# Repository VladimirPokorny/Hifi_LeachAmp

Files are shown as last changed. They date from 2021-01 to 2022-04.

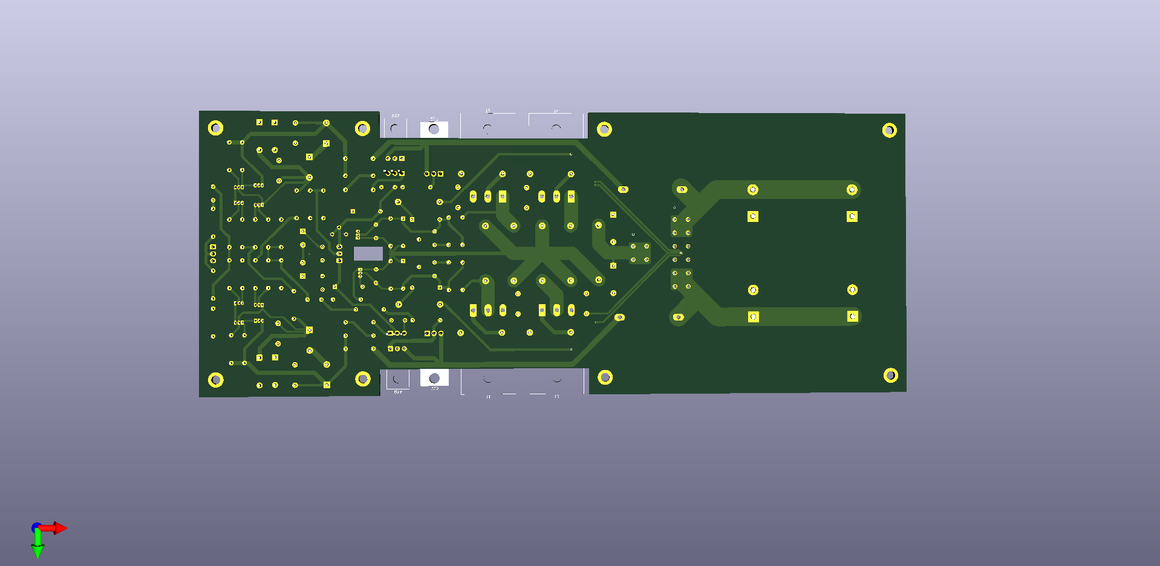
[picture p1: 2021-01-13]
LeachAmp_kicad/export_obr/3D_pohled_2.png

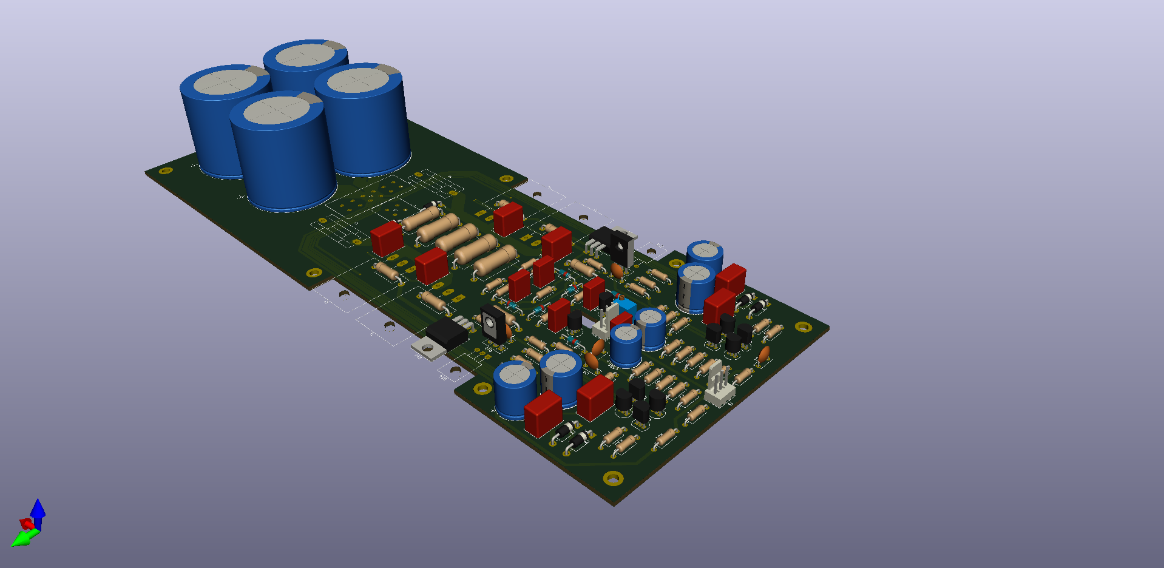
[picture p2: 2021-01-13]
LeachAmp_kicad/export_obr/3D_pohled_3.png

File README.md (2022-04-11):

# Hifi_LeachAmp

Design of low frequency audio amplifier designed by Prof. Leach from Georgia Institute of Technology.
Main resource: https://leachlegacy.ece.gatech.edu/lowtim/

The PCB is designated in freeware software KiCAD. https://www.kicad.org/

The project is not finished yet. It has been put on hold due to work on the Master's thesis.

LeachAmp

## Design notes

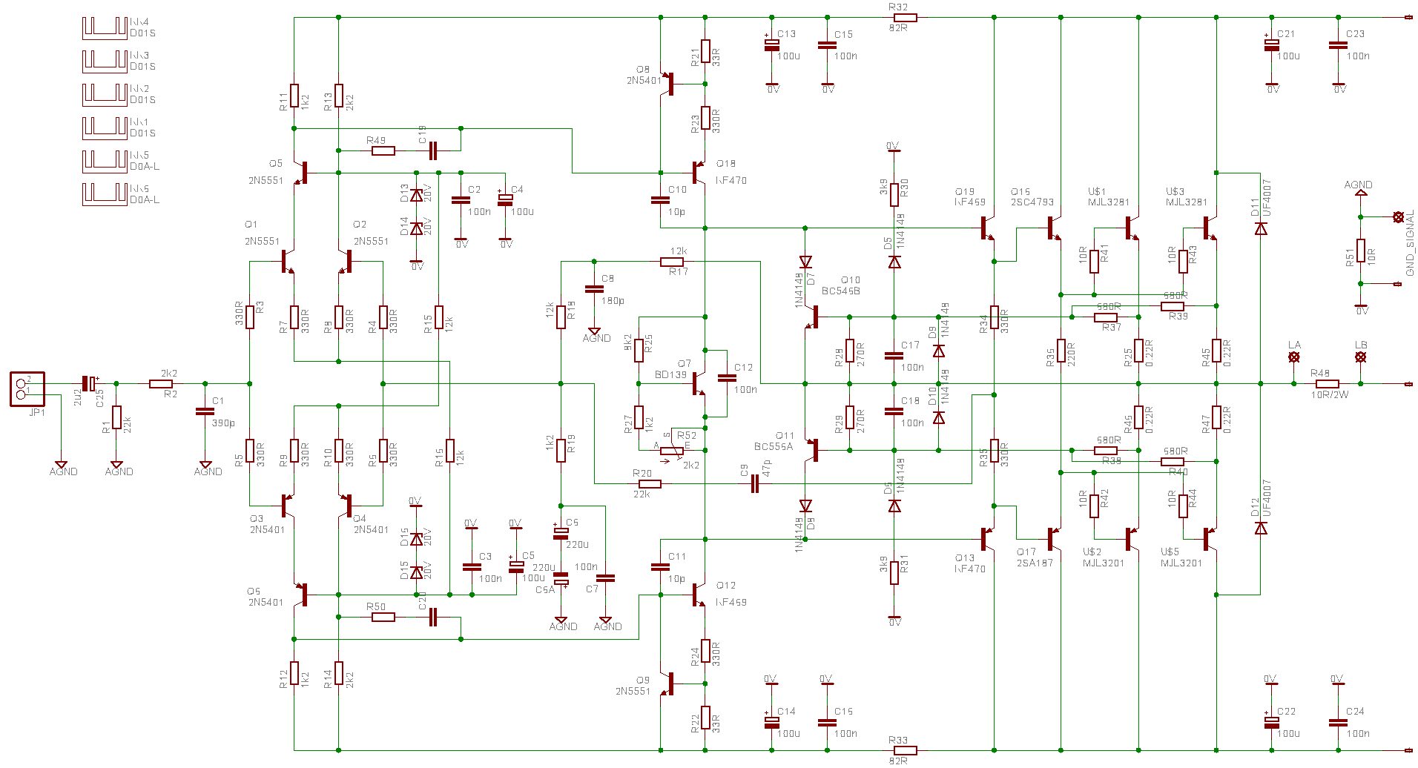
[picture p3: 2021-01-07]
Podklady/Levex_Leach_schema.PNG

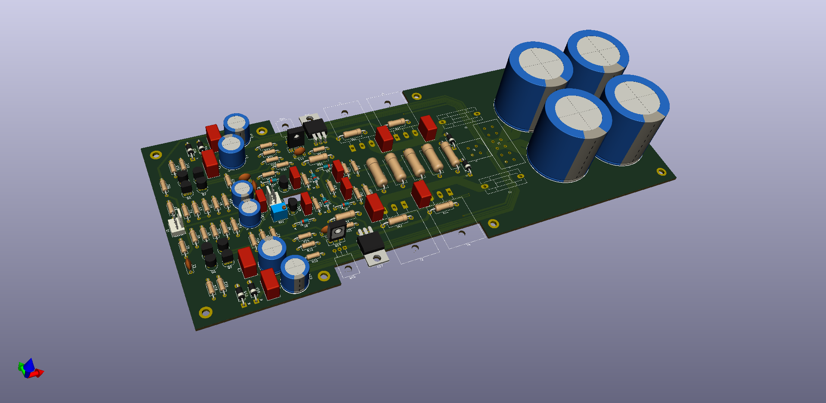
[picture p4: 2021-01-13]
LeachAmp_kicad/export_obr/3D_pohled_1.png

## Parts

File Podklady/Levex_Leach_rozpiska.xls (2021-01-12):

Rozpiska součástek pro Leach LV-edition
Označení | Hodnota | Popis
C1 | 390p | RM=5
C2 | 100n/50V | RM=5
C3 | 100n/50V | RM=5
C4 | 100u/63V | RM=5
C5 | 100u/63V | RM=5
C6 | 100u/63V | RM=5 (nebo osadit bipolárním a C6A spojit propojkou)
C6A | 100u/63V | RM=5
C7 | 100n | RM=5 (fóliový)
C8 | 180p | RM=5
C9 | 47p | RM=5
C10 | 10p/500V | RM=5
C11 | 10p/500V | RM=5
C12 | 100n/50V | RM=5
C13 | 100u/63V | RM=5
C14 | 100u/63V | RM=5
C15 | 100n/63V | RM=5
C16 | 100n/63V | RM=5
C17 | 100n/50V | RM=5
C18 | 100n/50V | RM=5
C19 | NEOSAZ. | 0805
C20 | NEOSAZ. | 0805
C21 | 100u/min 63V | RM=5
C22 | 100u/min 63V | RM=5
C23 | 100n/min 63V | RM=5
C24 | 100n/min 63V | RM=5
C25 | 2u2/35V | RM=2,5
D5 | 1N4148 | RM=10
D6 | 1N4148 | RM=10
D7 | 1N4148 | RM=10
D8 | 1N4148 | RM=10
D9 | 1N4148 | RM=10
D10 | 1N4148 | RM=10
D11 | UF4007 | RM=10
D12 | UF4007 | RM=10
D13 | ZD20V | RM=10
D14 | ZD20V | RM=10
D15 | ZD20V | RM=10
D16 | ZD20V | RM=10
Q1 | BC546B | (nebo 2N5551 - ale otočit o 180°)
Q2 | BC546B | (nebo 2N5551 - ale otočit o 180°)
Q3 | BC556B | (nebo 2N5401 - ale otočit o 180°)
Q4 | BC556B | (nebo 2N5401 - ale otočit o 180°)
Q5 | BC546B | (nebo 2N5551 - ale otočit o 180°)
Q6 | BC556B | (nebo 2N5401 - ale otočit o 180°)
Q7 | KF469 | případně BF469 nebo BF471)
Q8 | BC556B | (nebo 2N5401 - ale otočit o 180°)
Q9 | BC546B | (nebo 2N5551 - ale otočit o 180°)
Q10 | BC546B | (nebo 2N5551 - ale otočit o 180°)
Q11 | BC556B | (nebo 2N5401 - ale otočit o 180°)
Q12 | KF469 | případně BF469 nebo BF471)
Q13 | KF470 | případně BF470 nebo BF472)
Q16 | 2SC4793 | TO-220
Q17 | 2SA1837 | TO-220
Q18 | KF470 | případně BF470 nebo BF472)
Q19 | KF469 | případně BF469 nebo BF471)
R1 | 22k | RM=10
R2 | 2k2 | RM=10
R3 | 330R | RM=10
R4 | 330R | RM=10
R5 | 330R | RM=10
R6 | 330R | RM=10
R7 | 330R | RM=10
R8 | 330R | RM=10
R9 | 330R | RM=10
R10 | 330R | RM=10
R11 | 1k2 | RM=10
R12 | 1k2 | RM=10
R13 | 2k2 | RM=12
R14 | 2k2 | RM=12
R15 | 12k | RM=10
R16 | 12k | RM=10
R17 | 12k | RM=10
R18 | 12k | RM=10
R19 | 1k2 | RM=10
R20 | 22k | RM=10
R21 | 33R | RM=10
R22 | 33R | RM=10
R23 | 330R | RM=10
R24 | 330R | RM=10
R25 | 0.22R/4W | RM=15
R26 | 8k2 | RM=10 (pokud bude klidový proud velký, tento odpor zmenšit)
R27 | 1k2 | RM=10
R28 | 270R | RM=10
R29 | 270R | RM=10
R30 | 3k9 | RM=12
R31 | 3k9 | RM=12
R32 | 82R | RM=10
R33 | 82R | RM=10
R34 | 330R | RM=10
R35 | 330R | RM=10
R36 | 220R | RM=10
R37 | 680R | RM=10
R38 | 680R | RM=10
R39 | 680R | RM=10
R40 | 680R | RM=10
R41 | 10R/2W | RM=12
R42 | 10R/2W | RM=12
R43 | 10R/2W | RM=12
R44 | 10R/2W | RM=12
R45 | 0.22R/4W | RM=15
R46 | 0.22R/4W | RM=15
R47 | 0.22R/4W | RM=15
R48 | 10R/2W | RM=15
R49 | NEOSAZ. | 0805
R50 | NEOSAZ. | 0805
R51 | 10R | RM=10
R52 | 2k5 | víceotáčkový
T1 | MJL3281A | TO-264
T2 | MJL3281A | TO-264
T3 | MJL1302A | TO-264
T4 | MJL1302A | TO-264
LA-LB | cívka | Namotat drátem d=1mm asi 12záv a nasadit na odpor R48

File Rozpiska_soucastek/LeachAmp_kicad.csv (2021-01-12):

Reference | Value | Footprint | Datasheet
R1 | 22k | Resistor_THT:R_Axial_DIN0207_L6.3mm_D2.5mm_P10.16mm_Horizontal | ~
R2 | 2k2 | Resistor_THT:R_Axial_DIN0207_L6.3mm_D2.5mm_P10.16mm_Horizontal | ~
R3 | 300R | Resistor_THT:R_Axial_DIN0207_L6.3mm_D2.5mm_P10.16mm_Horizontal | ~
R7 | 300R | Resistor_THT:R_Axial_DIN0207_L6.3mm_D2.5mm_P10.16mm_Horizontal | ~
R8 | 300R | Resistor_THT:R_Axial_DIN0207_L6.3mm_D2.5mm_P10.16mm_Horizontal | ~
R11 | 1k2 | Resistor_THT:R_Axial_DIN0207_L6.3mm_D2.5mm_P10.16mm_Horizontal | ~
R13 | 2k2 | Resistor_THT:R_Axial_DIN0207_L6.3mm_D2.5mm_P10.16mm_Horizontal | ~
D13 | 20V/0,5W | Diode_THT:D_DO-41_SOD81_P10.16mm_Horizontal | ~
D14 | 20V/0,5W | Diode_THT:D_DO-41_SOD81_P10.16mm_Horizontal | ~
R4 | 300R | Resistor_THT:R_Axial_DIN0207_L6.3mm_D2.5mm_P10.16mm_Horizontal | ~
R5 | 300R | Resistor_THT:R_Axial_DIN0207_L6.3mm_D2.5mm_P10.16mm_Horizontal | ~
R9 | 300R | Resistor_THT:R_Axial_DIN0207_L6.3mm_D2.5mm_P10.16mm_Horizontal | ~
R10 | 300R | Resistor_THT:R_Axial_DIN0207_L6.3mm_D2.5mm_P10.16mm_Horizontal | ~
R12 | 1k2 | Resistor_THT:R_Axial_DIN0207_L6.3mm_D2.5mm_P10.16mm_Horizontal | ~
R14 | 2k2 | Resistor_THT:R_Axial_DIN0207_L6.3mm_D2.5mm_P10.16mm_Horizontal | ~
R6 | 300R | Resistor_THT:R_Axial_DIN0207_L6.3mm_D2.5mm_P10.16mm_Horizontal | ~
R15 | 12k | Resistor_THT:R_Axial_DIN0207_L6.3mm_D2.5mm_P10.16mm_Horizontal | ~
R16 | 12k | Resistor_THT:R_Axial_DIN0207_L6.3mm_D2.5mm_P10.16mm_Horizontal | ~
C2 | 100n/100V film | Capacitor_THT:C_Rect_L10.3mm_W5.7mm_P7.50mm_MKS4 | ~
R19 | 1k1 | Resistor_THT:R_Axial_DIN0207_L6.3mm_D2.5mm_P10.16mm_Horizontal | ~
R18 | 1k1 | Resistor_THT:R_Axial_DIN0207_L6.3mm_D2.5mm_P10.16mm_Horizontal | ~
R21 | 30R | Resistor_THT:R_Axial_DIN0207_L6.3mm_D2.5mm_P10.16mm_Horizontal | ~
R23 | 360R | Resistor_THT:R_Axial_DIN0207_L6.3mm_D2.5mm_P10.16mm_Horizontal | ~
C10 | 10p | Capacitor_THT:C_Disc_D6.0mm_W2.5mm_P5.00mm | ~
C8 | 180p | Capacitor_THT:C_Disc_D6.0mm_W2.5mm_P5.00mm | ~
R25 | 8k2 | Resistor_THT:R_Axial_DIN0207_L6.3mm_D2.5mm_P10.16mm_Horizontal | ~
Q7 | BD139 | Package_TO_SOT_THT:TO-92_Inline | http://www.onsemi.com/pub_link/Collateral/MPSA42-D.PDF
C12 | 100n/50V film | Capacitor_THT:C_Rect_L7.2mm_W3.5mm_P5.00mm_FKS2_FKP2_MKS2_MKP2 | ~
R27 | 1k2 | Resistor_THT:R_Axial_DIN0207_L6.3mm_D2.5mm_P10.16mm_Horizontal | ~
R28 | 270R | Resistor_THT:R_Axial_DIN0207_L6.3mm_D2.5mm_P10.16mm_Horizontal | ~
R22 | 30R | Resistor_THT:R_Axial_DIN0207_L6.3mm_D2.5mm_P10.16mm_Horizontal | ~
R24 | 360R | Resistor_THT:R_Axial_DIN0207_L6.3mm_D2.5mm_P10.16mm_Horizontal | ~
C11 | 10p | Capacitor_THT:C_Disc_D6.0mm_W2.5mm_P5.00mm | ~
C4 | 100u/63V | Capacitor_THT:CP_Radial_D12.5mm_P7.50mm | ~
C3 | 100n/100V film | Capacitor_THT:C_Rect_L10.3mm_W5.7mm_P7.50mm_MKS4 | ~
C5 | 100u/63V | Capacitor_THT:CP_Radial_D12.5mm_P7.50mm | ~
C6A1 | 330u/16V | Capacitor_THT:CP_Radial_D10.0mm_P5.00mm | ~
C6B1 | 330u/16V | Capacitor_THT:CP_Radial_D10.0mm_P5.00mm | ~
C7 | 100n/50V film | Capacitor_THT:C_Rect_L7.2mm_W3.5mm_P5.00mm_FKS2_FKP2_MKS2_MKP2 | ~
C14 | 100u/63V | Capacitor_THT:CP_Radial_D12.5mm_P7.50mm | ~
C16 | 100n/100V film | Capacitor_THT:C_Rect_L10.3mm_W5.7mm_P7.50mm_MKS4 | ~
C15 | 100n/100V | Capacitor_THT:C_Rect_L10.3mm_W5.7mm_P7.50mm_MKS4 | ~
R32 | 82R | Resistor_THT:R_Axial_DIN0207_L6.3mm_D2.5mm_P10.16mm_Horizontal | ~
Q10 | MPSA06 | Package_TO_SOT_THT:TO-92_Inline | http://www.onsemi.com/pub_link/Collateral/MPSA42-D.PDF
D7 | 1N4148 | Diode_THT:D_DO-35_SOD27_P10.16mm_Horizontal | ~
Q11 | MPSA56 | Package_TO_SOT_THT:TO-92_Inline | http://www.onsemi.com/pub_link/Collateral/MPSA92-D.PDF
R29 | 270R | Resistor_THT:R_Axial_DIN0207_L6.3mm_D2.5mm_P10.16mm_Horizontal | ~
C17 | 100n/50V film | Capacitor_THT:C_Rect_L7.2mm_W3.5mm_P5.00mm_FKS2_FKP2_MKS2_MKP2 | ~
C18 | 100n/50V film | Capacitor_THT:C_Rect_L7.2mm_W3.5mm_P5.00mm_FKS2_FKP2_MKS2_MKP2 | ~
D9 | 1N4148 | Diode_THT:D_DO-35_SOD27_P10.16mm_Horizontal | ~
D10 | 1N4148 | Diode_THT:D_DO-35_SOD27_P10.16mm_Horizontal | ~
D8 | 1N4148 | Diode_THT:D_DO-35_SOD27_P10.16mm_Horizontal | ~
R31 | 3k9 0,5W | Resistor_THT:R_Axial_DIN0411_L9.9mm_D3.6mm_P15.24mm_Horizontal | ~
Q15 | BF470 | Package_TO_SOT_THT:TO-126-3_Horizontal_TabDown | http://www.onsemi.com/pub_link/Collateral/MPSA92-D.PDF
R35 | 330R | Resistor_THT:R_Axial_DIN0207_L6.3mm_D2.5mm_P10.16mm_Horizontal | ~
R30 | 3k9 0,5W | Resistor_THT:R_Axial_DIN0411_L9.9mm_D3.6mm_P15.24mm_Horizontal | ~
Q14 | BF469 | Package_TO_SOT_THT:TO-126-3_Horizontal_TabDown | http://www.onsemi.com/pub_link/Collateral/MPSA42-D.PDF
Q16 | MJE15030 | Package_TO_SOT_THT:TO-220-3_Horizontal_TabDown | http://www.onsemi.com/pub_link/Collateral/MPSA42-D.PDF
D5 | 1N4148 | Diode_THT:D_DO-35_SOD27_P10.16mm_Horizontal | ~
R34 | 330R | Resistor_THT:R_Axial_DIN0207_L6.3mm_D2.5mm_P10.16mm_Horizontal | ~
R36 | 220R | Resistor_THT:R_Axial_DIN0207_L6.3mm_D2.5mm_P10.16mm_Horizontal | ~
R37 | 680R | Resistor_THT:R_Axial_DIN0207_L6.3mm_D2.5mm_P10.16mm_Horizontal | ~
R42 | 10R 0,5 W | Resistor_THT:R_Axial_DIN0411_L9.9mm_D3.6mm_P15.24mm_Horizontal | ~
R33 | 82R | Resistor_THT:R_Axial_DIN0207_L6.3mm_D2.5mm_P10.16mm_Horizontal | ~
R49 | 10R 2W | Resistor_THT:R_Axial_DIN0516_L15.5mm_D5.0mm_P20.32mm_Horizontal | ~
R38 | 680R | Resistor_THT:R_Axial_DIN0207_L6.3mm_D2.5mm_P10.16mm_Horizontal | ~
R43 | 10R 0,5W | Resistor_THT:R_Axial_DIN0411_L9.9mm_D3.6mm_P15.24mm_Horizontal | ~
C21 | CP | Capacitor_THT:CP_Radial_D35.0mm_P10.00mm_SnapIn | ~
R41 | 10R 0,5W | Resistor_THT:R_Axial_DIN0411_L9.9mm_D3.6mm_P15.24mm_Horizontal | ~
R39 | 680R | Resistor_THT:R_Axial_DIN0207_L6.3mm_D2.5mm_P10.16mm_Horizontal | ~
C19 | 10n/50V film | Capacitor_THT:C_Rect_L7.2mm_W3.5mm_P5.00mm_FKS2_FKP2_MKS2_MKP2 | ~
C20 | 10n/50V film | Capacitor_THT:C_Rect_L7.2mm_W3.5mm_P5.00mm_FKS2_FKP2_MKS2_MKP2 | ~
C9 | 47p | Capacitor_THT:C_Disc_D6.0mm_W2.5mm_P5.00mm | ~
R20 | 22k | Resistor_THT:R_Axial_DIN0207_L6.3mm_D2.5mm_P10.16mm_Horizontal | ~
R45 | 0,33R 5W | Resistor_THT:R_Axial_DIN0617_L17.0mm_D6.0mm_P20.32mm_Horizontal | ~
R40 | 680R | Resistor_THT:R_Axial_DIN0207_L6.3mm_D2.5mm_P10.16mm_Horizontal | ~
D12 | 1N4007 | Diode_THT:D_DO-41_SOD81_P10.16mm_Horizontal | ~
D11 | 1N4007 | Diode_THT:D_DO-41_SOD81_P10.16mm_Horizontal | ~
C22 | CP | Capacitor_THT:CP_Radial_D35.0mm_P10.00mm_SnapIn | ~
R51 | 82R | Resistor_THT:R_Axial_DIN0207_L6.3mm_D2.5mm_P10.16mm_Horizontal | ~
C1 | 390pF | Capacitor_THT:C_Disc_D6.0mm_W2.5mm_P5.00mm | ~
D16 | 20V/0,5W | Diode_THT:D_DO-41_SOD81_P10.16mm_Horizontal | ~
D15 | 20V/0,5W | Diode_THT:D_DO-41_SOD81_P10.16mm_Horizontal | ~
C13 | 100u/63V | Capacitor_THT:CP_Radial_D12.5mm_P7.50mm | ~
D6 | 1N4148 | Diode_THT:D_DO-35_SOD27_P10.16mm_Horizontal | ~
Q17 | MJE15031 | Package_TO_SOT_THT:TO-220-3_Horizontal_TabDown | http://www.onsemi.com/pub_link/Collateral/MPSA92-D.PDF
R46 | 0,33R 5W | Resistor_THT:R_Axial_DIN0617_L17.0mm_D6.0mm_P20.32mm_Horizontal | ~
R47 | 0,33R 5W | Resistor_THT:R_Axial_DIN0617_L17.0mm_D6.0mm_P20.32mm_Horizontal | ~
R44 | 10R 0,5W | Resistor_THT:R_Axial_DIN0411_L9.9mm_D3.6mm_P15.24mm_Horizontal | ~
R48 | 0,33R 5W | Resistor_THT:R_Axial_DIN0617_L17.0mm_D6.0mm_P20.32mm_Horizontal | ~
R17 | 11k | Resistor_THT:R_Axial_DIN0207_L6.3mm_D2.5mm_P10.16mm_Horizontal | ~
C24 | 100n/100V film | Capacitor_THT:C_Rect_L10.3mm_W5.7mm_P7.50mm_MKS4 | ~
C23 | 100n/100V film | Capacitor_THT:C_Rect_L10.3mm_W5.7mm_P7.50mm_MKS4 | ~
C25 | CP | Capacitor_THT:CP_Radial_D35.0mm_P10.00mm_SnapIn | ~
C26 | CP | Capacitor_THT:CP_Radial_D35.0mm_P10.00mm_SnapIn | ~
RV1 | 2k | Potentiometer_THT:Potentiometer_Bourns_3266W_Vertical | ~
F1 | Fuse | Fuse_Holders_and_Fuses:Fuseholder5x20_horiz_SemiClosed_Casing10x25mm | ~
F2 | Fuse | Fuse_Holders_and_Fuses:Fuseholder5x20_horiz_SemiClosed_Casing10x25mm | ~
C6 | 100n/100V film | Capacitor_THT:C_Rect_L10.3mm_W5.7mm_P7.50mm_MKS4 | ~
C27 | 100n/100V film | Capacitor_THT:C_Rect_L10.3mm_W5.7mm_P7.50mm_MKS4 | ~
J3 | Conn_01x03_Female | Connector_Molex:Molex_KK-254_AE-6410-03A_1x03_P2.54mm_Vertical | ~
Q5 | BC546 | Package_TO_SOT_THT:TO-92_Inline | http://www.fairchildsemi.com/ds/BC/BC547.pdf
Q1 | BC546 | Package_TO_SOT_THT:TO-92_Inline | http://www.fairchildsemi.com/ds/BC/BC547.pdf
Q2 | BC546 | Package_TO_SOT_THT:TO-92_Inline | http://www.fairchildsemi.com/ds/BC/BC547.pdf
Q3 | BC556 | Package_TO_SOT_THT:TO-92_Inline | http://www.fairchildsemi.com/ds/BC/BC557.pdf
Q4 | BC556 | Package_TO_SOT_THT:TO-92_Inline | http://www.fairchildsemi.com/ds/BC/BC557.pdf
Q6 | BC556 | Package_TO_SOT_THT:TO-92_Inline | http://www.fairchildsemi.com/ds/BC/BC557.pdf
Q9 | BC546 | Package_TO_SOT_THT:TO-92_Inline | http://www.fairchildsemi.com/ds/BC/BC547.pdf
Q13 | BF469 | Package_TO_SOT_THT:TO-126-3_Vertical | https://www.pcpaudio.com/pcpfiles/transistores/BF457-8-9.pdf
Q8 | BC556 | Package_TO_SOT_THT:TO-92_Inline | http://www.fairchildsemi.com/ds/BC/BC557.pdf
Q12 | BF470 | Package_TO_SOT_THT:TO-126-3_Vertical | http://pdf.datasheetcatalog.com/datasheet/sanyo/ds_pdf_e/2SB631.pdf
T1 | MJL3281 | Package_TO_SOT_THT:TO-264-3_Horizontal_TabDown | http://www.onsemi.com/pub_link/Collateral/2N3055-D.PDF
T3 | MJL3281 | Package_TO_SOT_THT:TO-264-3_Horizontal_TabDown | http://www.onsemi.com/pub_link/Collateral/2N3055-D.PDF
T2 | MJL3201 | Package_TO_SOT_THT:TO-264-3_Horizontal_TabDown | http://www.onsemi.com/pub_link/Collateral/MPSA92-D.PDF
T4 | MJL3201 | Package_TO_SOT_THT:TO-264-3_Horizontal_TabDown | http://www.onsemi.com/pub_link/Collateral/MPSA92-D.PDF
J1 | Conn_01x12_Female | LeachAmp_library:Wago-256-406 | ~
J2 | Conn_01x04_Female | LeachAmp_library:Wago-256-402 | ~
J4 | Conn_01x03_Female | Connector_Molex:Molex_KK-254_AE-6410-03A_1x03_P2.54mm_Vertical | ~

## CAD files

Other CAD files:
LeachAmp_3D_model/OldVersions/Zesilovac.0001.iam
LeachAmp_3D_model/OldVersions/chladic.0003.ipt
LeachAmp_3D_model/Predni_strana.ipt
LeachAmp_3D_model/Viko-horni.ipt
LeachAmp_3D_model/Zadni_strana.ipt
LeachAmp_3D_model/Zesilovac.iam
LeachAmp_3D_model/chladic.ipt

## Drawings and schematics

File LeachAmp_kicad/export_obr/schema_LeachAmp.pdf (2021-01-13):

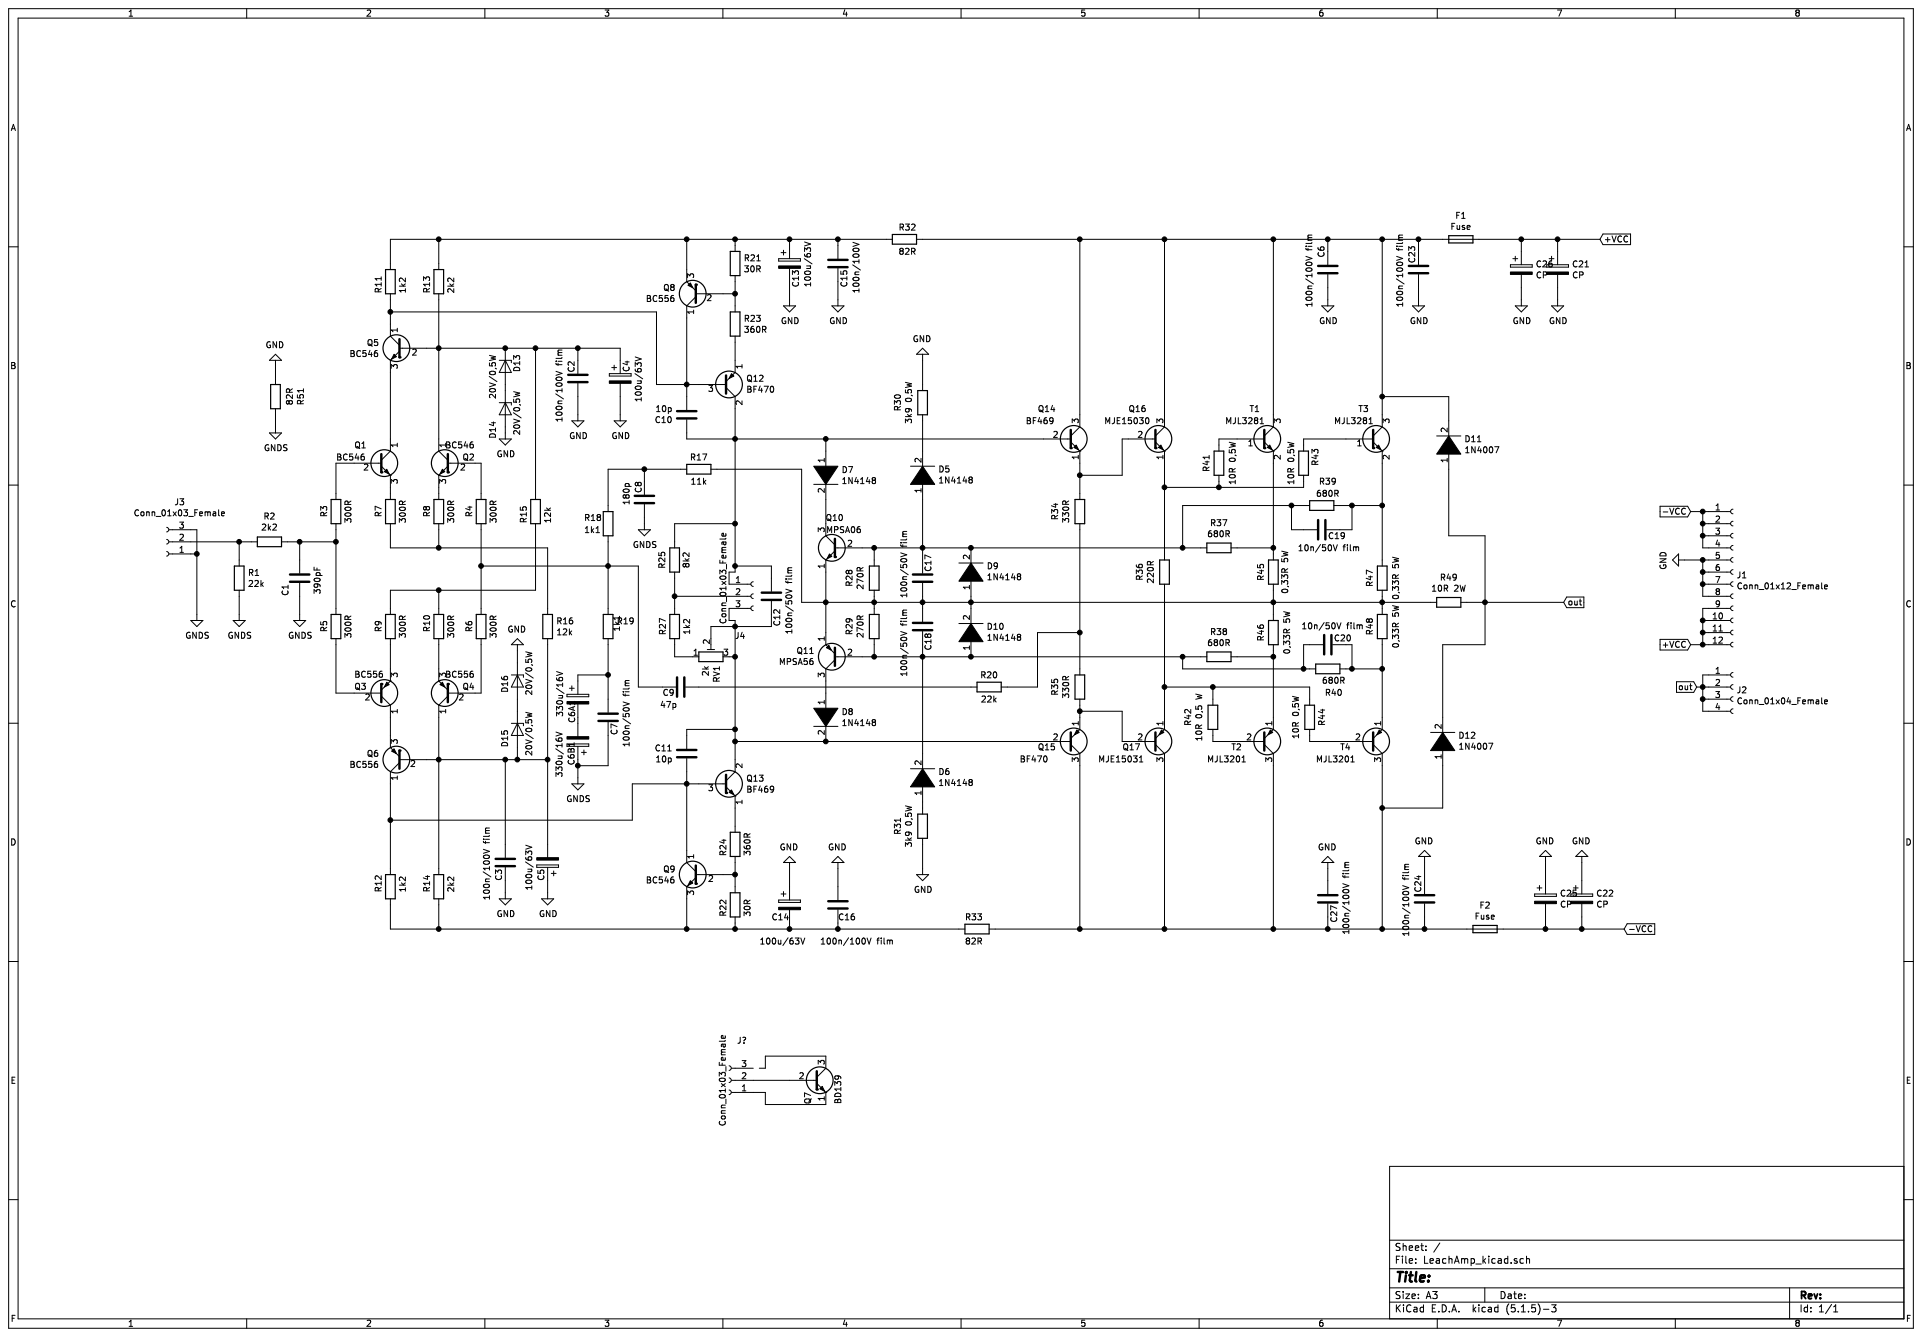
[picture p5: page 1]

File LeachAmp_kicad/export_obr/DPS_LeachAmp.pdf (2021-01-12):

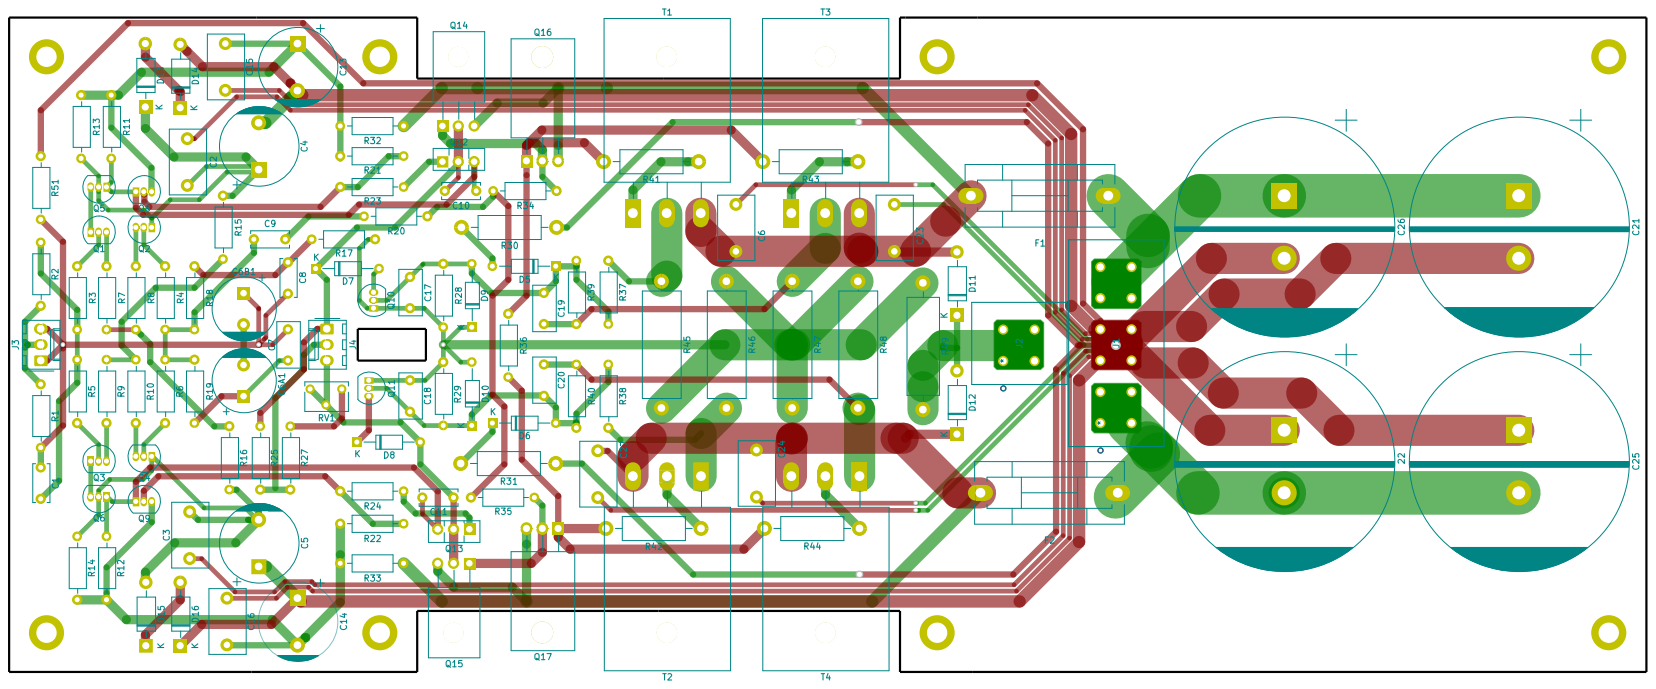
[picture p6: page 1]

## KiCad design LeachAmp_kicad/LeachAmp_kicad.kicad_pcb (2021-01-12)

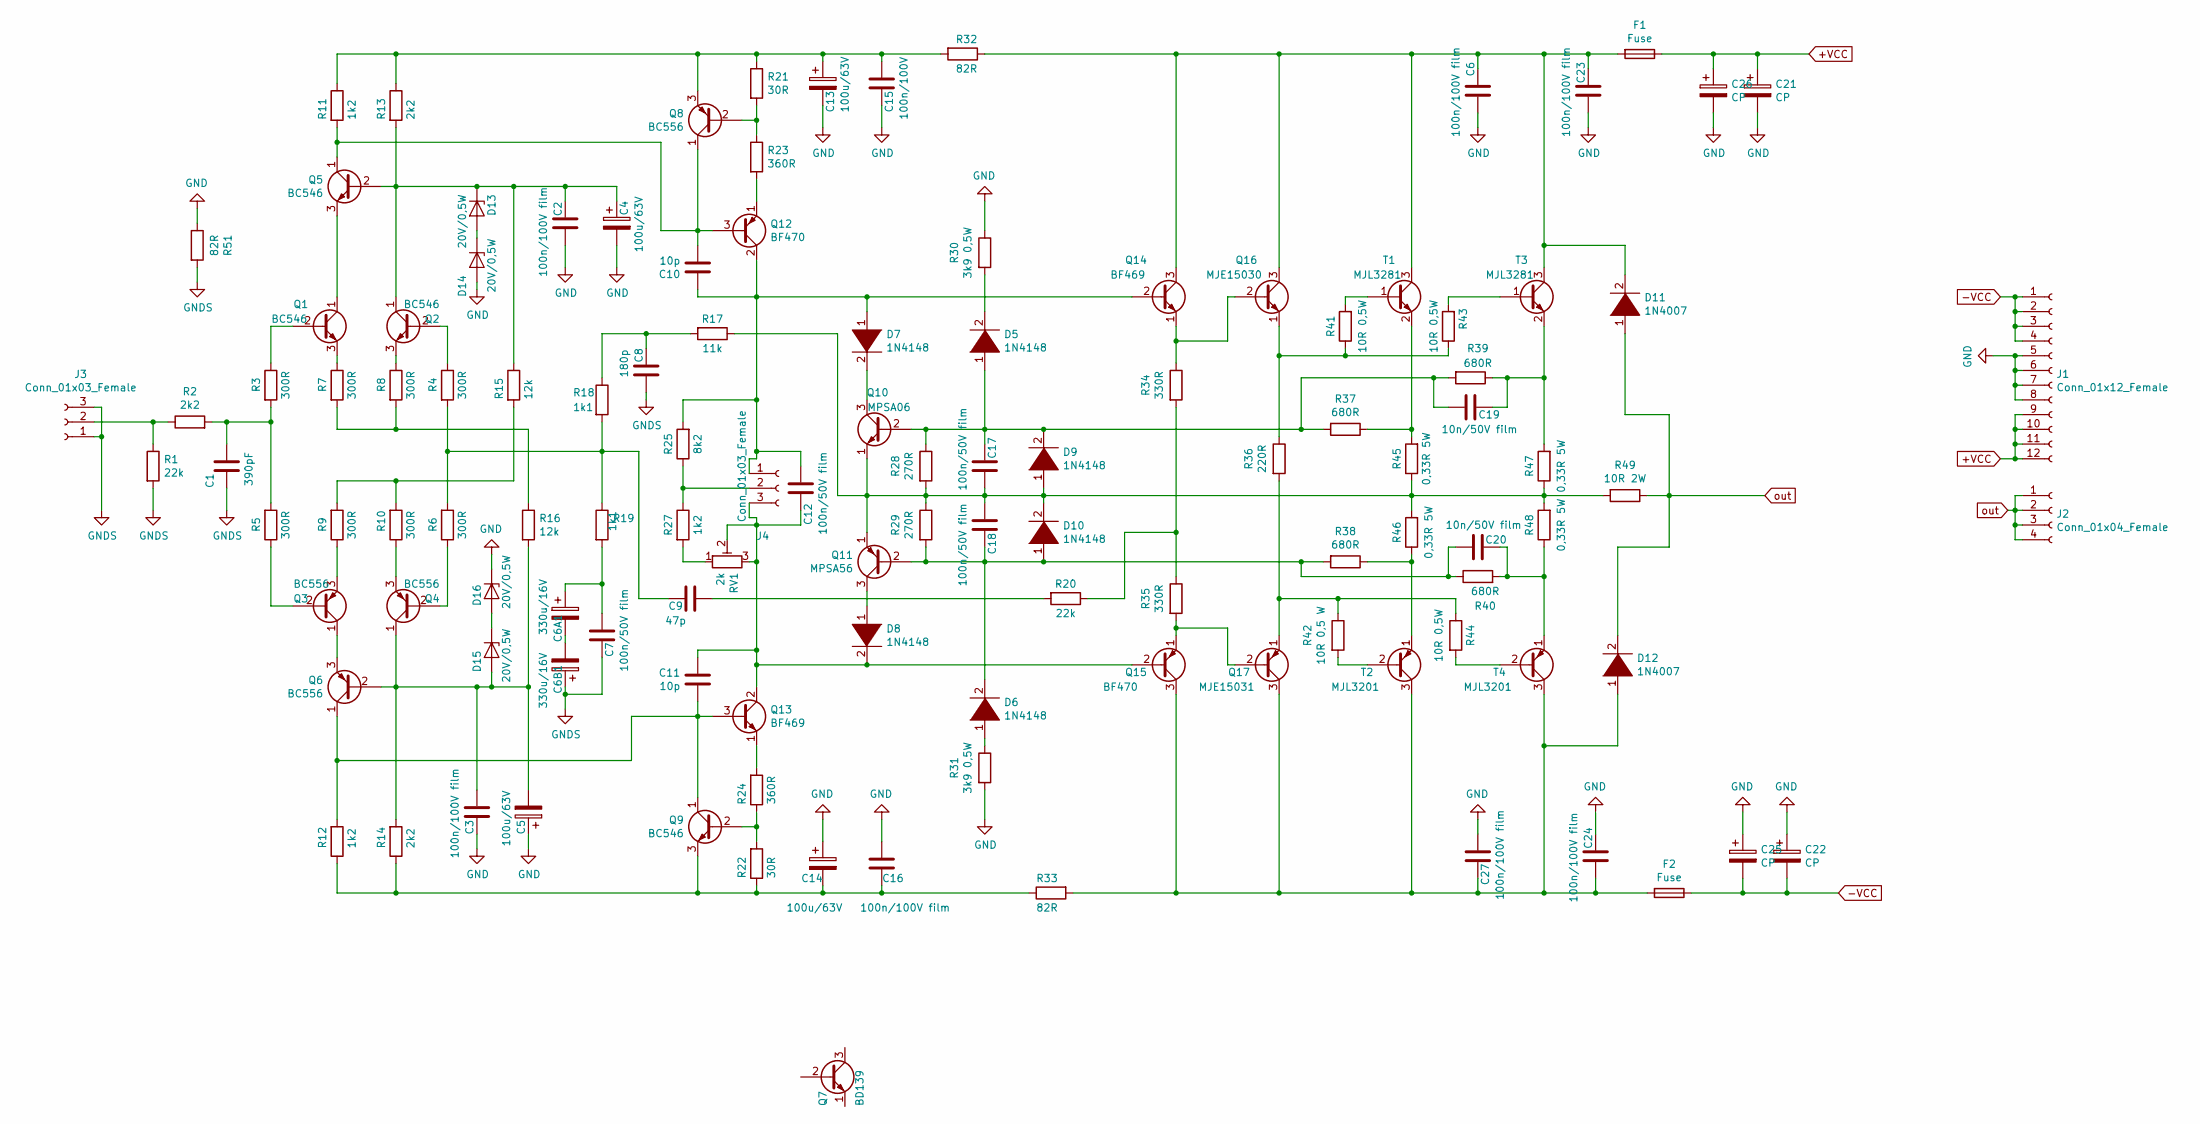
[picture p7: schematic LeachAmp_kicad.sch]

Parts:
C1: 390pF; C_Disc_D6.0mm_W2.5mm_P5.00mm
C2, C3, C6, C16, C23, C24, C27: 100n/100V film; C_Rect_L10.3mm_W5.7mm_P7.50mm_MKS4
C4, C5, C13, C14: 100u/63V; CP_Radial_D12.5mm_P7.50mm
C6A1, C6B1: 330u/16V; CP_Radial_D10.0mm_P5.00mm
C7, C12, C17, C18: 100n/50V film; C_Rect_L7.2mm_W3.5mm_P5.00mm_FKS2_FKP2_MKS2_MKP2
C8: 180p; C_Disc_D6.0mm_W2.5mm_P5.00mm
C9: 47p; C_Disc_D6.0mm_W2.5mm_P5.00mm
C10, C11: 10p; C_Disc_D6.0mm_W2.5mm_P5.00mm
C15: 100n/100V; C_Rect_L10.3mm_W5.7mm_P7.50mm_MKS4
C19, C20: 10n/50V film; C_Rect_L7.2mm_W3.5mm_P5.00mm_FKS2_FKP2_MKS2_MKP2
C21, C22, C25, C26: CP; CP_Radial_D35.0mm_P10.00mm_SnapIn
D5, D6, D7, D8, D9, D10: 1N4148; D_DO-35_SOD27_P10.16mm_Horizontal
D11, D12: 1N4007; D_DO-41_SOD81_P10.16mm_Horizontal
D13, D14, D15, D16: 20V/0,5W; D_DO-41_SOD81_P10.16mm_Horizontal
F1, F2: Fuse; Fuseholder5x20_horiz_SemiClosed_Casing10x25mm
J1: Conn_01x12_Female; Wago-256-406
J2: Conn_01x04_Female; Wago-256-402
J3, J4: Conn_01x03_Female; Molex_KK-254_AE-6410-03A_1x03_P2.54mm_Vertical
Q1, Q2, Q5, Q9: BC546; TO-92_Inline
Q3, Q4, Q6, Q8: BC556; TO-92_Inline
Q7: BD139; TO-92_Inline
Q10: MPSA06; TO-92_Inline
Q11: MPSA56; TO-92_Inline
Q12: BF470; TO-126-3_Vertical
Q13: BF469; TO-126-3_Vertical
Q14: BF469; TO-126-3_Horizontal_TabDown
Q15: BF470; TO-126-3_Horizontal_TabDown
Q16: MJE15030; TO-220-3_Horizontal_TabDown
Q17: MJE15031; TO-220-3_Horizontal_TabDown
R1, R20: 22k; R_Axial_DIN0207_L6.3mm_D2.5mm_P10.16mm_Horizontal
R2, R13, R14: 2k2; R_Axial_DIN0207_L6.3mm_D2.5mm_P10.16mm_Horizontal
R3, R4, R5, R6, R7, R8, R9, R10: 300R; R_Axial_DIN0207_L6.3mm_D2.5mm_P10.16mm_Horizontal
R11, R12, R27: 1k2; R_Axial_DIN0207_L6.3mm_D2.5mm_P10.16mm_Horizontal
R15, R16: 12k; R_Axial_DIN0207_L6.3mm_D2.5mm_P10.16mm_Horizontal
R17: 11k; R_Axial_DIN0207_L6.3mm_D2.5mm_P10.16mm_Horizontal
R18, R19: 1k1; R_Axial_DIN0207_L6.3mm_D2.5mm_P10.16mm_Horizontal
R21, R22: 30R; R_Axial_DIN0207_L6.3mm_D2.5mm_P10.16mm_Horizontal
R23, R24: 360R; R_Axial_DIN0207_L6.3mm_D2.5mm_P10.16mm_Horizontal
R25: 8k2; R_Axial_DIN0207_L6.3mm_D2.5mm_P10.16mm_Horizontal
R28, R29: 270R; R_Axial_DIN0207_L6.3mm_D2.5mm_P10.16mm_Horizontal
R30, R31: 3k9 0,5W; R_Axial_DIN0411_L9.9mm_D3.6mm_P15.24mm_Horizontal
R32, R33, R51: 82R; R_Axial_DIN0207_L6.3mm_D2.5mm_P10.16mm_Horizontal
R34, R35: 330R; R_Axial_DIN0207_L6.3mm_D2.5mm_P10.16mm_Horizontal
R36: 220R; R_Axial_DIN0207_L6.3mm_D2.5mm_P10.16mm_Horizontal
R37, R38, R39, R40: 680R; R_Axial_DIN0207_L6.3mm_D2.5mm_P10.16mm_Horizontal
R41, R43, R44: 10R 0,5W; R_Axial_DIN0411_L9.9mm_D3.6mm_P15.24mm_Horizontal
R42: 10R 0,5 W; R_Axial_DIN0411_L9.9mm_D3.6mm_P15.24mm_Horizontal
R45, R46, R47, R48: 0,33R 5W; R_Axial_DIN0617_L17.0mm_D6.0mm_P20.32mm_Horizontal
R49: 10R 2W; R_Axial_DIN0516_L15.5mm_D5.0mm_P20.32mm_Horizontal
RV1: 2k; Potentiometer_Bourns_3266W_Vertical
T1, T3: MJL3281; TO-264-3_Horizontal_TabDown
T2, T4: MJL3201; TO-264-3_Horizontal_TabDown

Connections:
+VCC: C21.1, C26.1, F1.1, J1.9, J1.10, J1.11, J1.12
-VCC: C22.2, C25.2, F2.1, J1.1, J1.2, J1.3, J1.4
GND: C2.1, C3.1, C4.2, C5.1, C6.1, C13.2, C14.1, C15.2, C16.1, C21.2, C22.1, C23.1, C24.2, C25.1, C26.2, C27.1, D14.2 (A), D16.1 (K), J1.5, J1.6, J1.7, J1.8, R30.1, R31.2, R51.1
GNDS: C1.1, C6B1.1, C7.2, C8.2, J3.1, J3.3, R1.2, R51.2
unnamed: C1.2, R2.2, R3.2, R5.2
unnamed: C2.2, C4.1, D13.1 (K), Q2.1 (C), Q5.2 (B), R13.2, R15.1
unnamed: C3.2, C5.2, D15.2 (A), Q4.1 (C), Q6.2 (B), R14.2, R16.2
unnamed: C6A1.1, C7.1, R19.2
unnamed: C6A1.2, C6B1.2
unnamed: C8.1, R17.2, R18.1
unnamed: C9.1, R4.2, R6.2, R18.2, R19.1
unnamed: C9.2, R20.2
unnamed: C10.1, C12.2, D7.1 (K), J4.1, Q12.2 (C), Q14.2 (B), R25.2
unnamed: C10.2, Q5.1 (C), Q8.1 (C), Q12.3 (B), R11.2
unnamed: C11.1, C12.1, D8.2 (A), J4.3, Q13.2 (C), Q15.2 (B), RV1.2, RV1.3
unnamed: C11.2, Q6.1 (C), Q9.1 (C), Q13.3 (B), R12.2
unnamed: C13.1, C15.1, Q8.3 (E), R11.1, R13.1, R21.1, R32.2
unnamed: C14.2, C16.2, Q9.3 (E), R12.1, R14.1, R22.1, R33.1
unnamed: C17.1, C18.2, D9.1 (K), D10.2 (A), Q10.1 (E), Q11.1 (E), R17.1, R28.2, R29.1, R45.1, R46.2, R47.1, R48.2, R49.2
unnamed: C17.2, C19.2, D5.1 (K), D9.2 (A), Q10.2 (B), R28.1, R37.2, R39.2
unnamed: C18.1, C20.1, D6.2 (A), D10.1 (K), Q11.2 (B), R29.2, R38.2, R40.1
unnamed: C19.1, R39.1, R47.2, T3.2 (E)
unnamed: C20.2, R40.2, R48.1, T4.1 (E)
unnamed: C6.2, C23.2, D11.2 (A), F1.2, Q14.3 (C), Q16.3 (C), R32.1, T1.3 (C), T3.3 (C)
unnamed: C24.1, C27.2, D12.1 (K), F2.2, Q15.3 (C), Q17.3 (C), R33.2, T2.3 (C), T4.3 (C)
unnamed: D5.2 (A), R30.2
unnamed: D6.1 (K), R31.1
unnamed: D7.2 (A), Q10.3 (C)
unnamed: D8.1 (K), Q11.3 (C)
unnamed: D13.2 (A), D14.1 (K)
unnamed: D15.1 (K), D16.2 (A)
unnamed: J3.2, R1.1, R2.1
unnamed: J4.2, R25.1, R27.1
unnamed: Q1.1 (C), Q5.3 (E)
unnamed: Q1.2 (B), R3.1
unnamed: Q1.3 (E), R7.1
unnamed: Q2.2 (B), R4.1
unnamed: Q2.3 (E), R8.1
unnamed: Q3.1 (C), Q6.3 (E)
unnamed: Q3.2 (B), R5.1
unnamed: Q3.3 (E), R9.1
unnamed: Q4.2 (B), R6.1
unnamed: Q4.3 (E), R10.1
unnamed: Q8.2 (B), R21.2, R23.1
unnamed: Q9.2 (B), R22.2, R24.1
unnamed: Q12.1 (E), R23.2
unnamed: Q13.1 (E), R24.2
unnamed: Q14.1 (E), Q16.2 (B), R34.1
unnamed: Q15.1 (E), Q17.2 (B), R35.2
unnamed: Q16.1 (E), R36.1, R41.1, R43.1
unnamed: Q17.1 (E), R36.2, R42.1, R44.1
unnamed: R9.2, R10.2, R15.2
unnamed: R7.2, R8.2, R16.1
unnamed: R20.1, R34.2, R35.1
unnamed: R27.2, RV1.1
unnamed: R37.1, R45.2, T1.2 (E)
unnamed: R38.1, R46.1, T2.1 (E)
unnamed: R41.2, T1.1 (B)
unnamed: R42.2, T2.2 (B)
unnamed: R43.2, T3.1 (B)
unnamed: R44.2, T4.2 (B)
out: D11.1 (K), D12.2 (A), J2.1, J2.2, J2.3, J2.4, R49.1

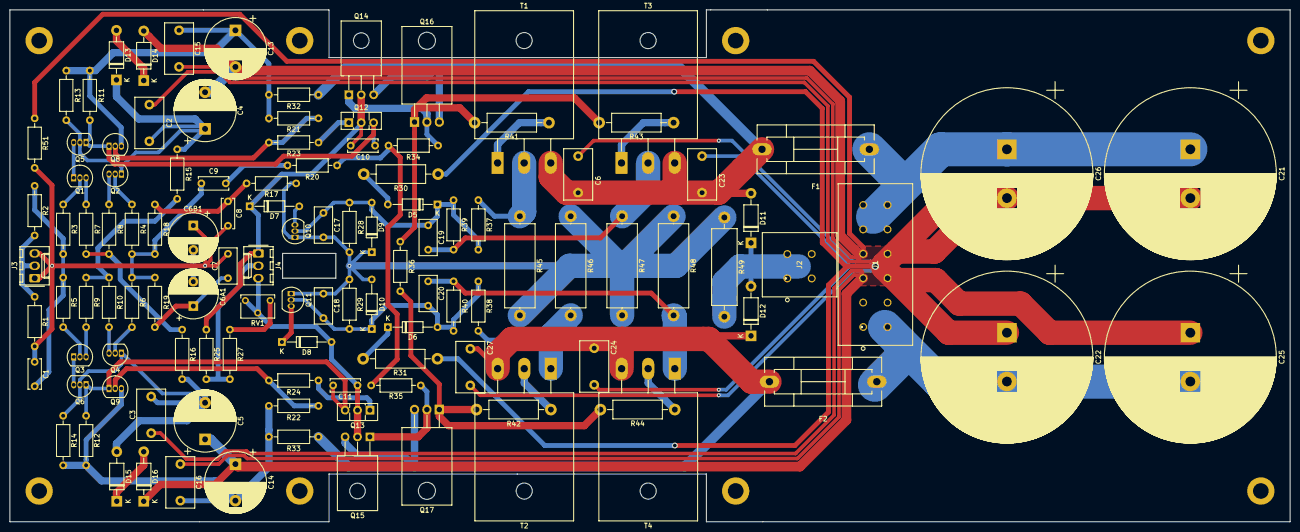
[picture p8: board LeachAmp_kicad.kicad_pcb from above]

Board: 2 copper layers, 262.4 x 104.9 mm, 124 parts (0 on the bottom side), 62 nets.

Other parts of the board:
 : MountingHole_3.2mm_M3_DIN965_Pad
 #2,  #3,  #4,  #5,  #6,  #7,  #8: MountingHole_3.2mm_M3_DIN965_Pad

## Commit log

2021-01-07 Schéma komplet + DPS v progresu
    Kompletní schéma Leach verze.
    DPS rozpracované - silová část
    [LeachAmp_kicad.kicad_pcb, LeachAmp_kicad.sch]
2021-01-08 DPS progress 70%
    DPS z většiny zpracovaná:
    Výkonová část 85 %;
    signální 60 %;
    zpětná vazba 20 %.
    [LeachAmp_kicad.kicad_pcb, LeachAmp_kicad.sch, Levex_Leach_rozpiska.xls]
2021-01-08 3D návrh
    Doplněn 3D návrh přední, zadní, strany, chladičů
    [Predni_strana.ipt, Viko-horni.ipt, Zadni_strana.ipt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]
2021-01-09 DPS progress 90 %
    signální 80 %;
    zpětná vazba 40 %.
    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
    [LeachAmp_kicad.kicad_pcb, LeachAmp_kicad.sch]
2021-01-10 DPS 100%
    [LeachAmp_kicad.kicad_pcb]
2021-01-10 DPS + rozpiska
    [LeachAmp_kicad.csv]
2021-01-12 DPS dokončeno
    [LeachAmp_kicad.kicad_pcb]

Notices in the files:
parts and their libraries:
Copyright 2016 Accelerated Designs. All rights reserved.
